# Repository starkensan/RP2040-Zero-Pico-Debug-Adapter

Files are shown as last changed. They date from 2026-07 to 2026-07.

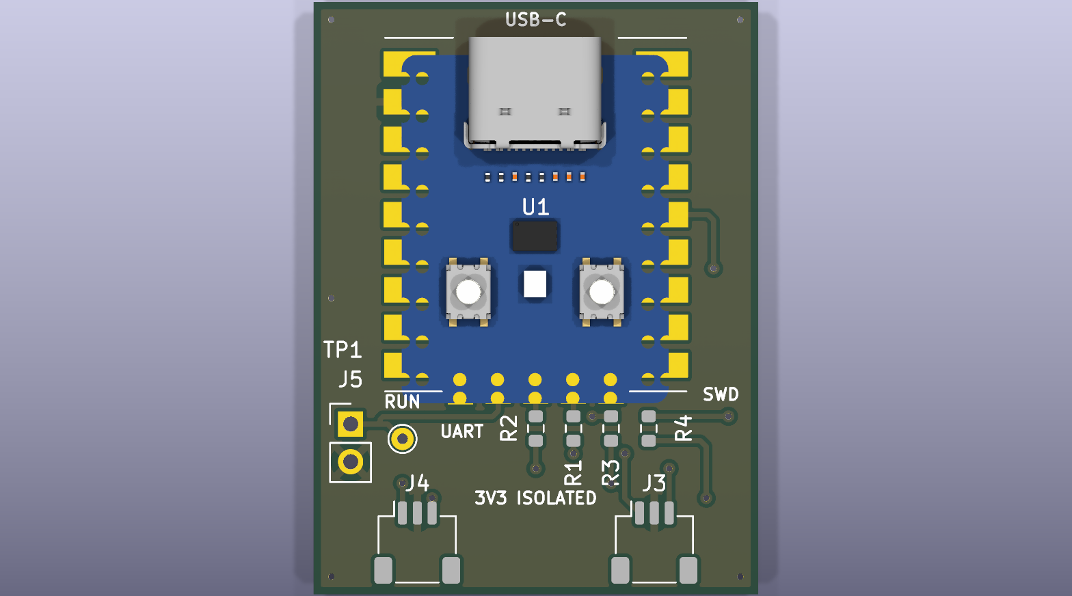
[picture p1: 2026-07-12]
RP2040-Zero-Pico-Debug-Adapter-preview.png

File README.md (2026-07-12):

# RP2040-Zero-Pico-Debug-Adapter

KiCad 9 project for a small 2-layer adapter PCB that mounts a Waveshare RP2040-Zero module and exposes the debugprobe-zero SWD/UART signals for Raspberry Pi Pico targets.

## Signal Mapping

| RP2040-Zero signal | Adapter part | Target connector pin |
| --- | --- | --- |
| GP10 | R1 100 ohm series | J3 pin 1 SWCLK |
| GND | direct | J3 pin 2 GND |
| GP11 | R2 100 ohm series | J3 pin 3 SWDIO |
| GP4 | R3 100 ohm series | J4 pin 1 TX from probe |
| GND | direct | J4 pin 2 GND |
| GP5 | R4 100 ohm series | J4 pin 3 RX to probe |
| GP12 | direct | J5 pin 1 RUN/RESET and TP1 |
| GND | direct | J5 pin 2 GND |

The RP2040-Zero 3V3 pin is not routed to the target connectors by default.

## Connectors

- `J3` Pico SWD JST-SH, 1.00 mm pitch:
  - Pin 1: `SWCLK`
  - Pin 2: `GND`
  - Pin 3: `SWDIO`
- `J4` UART JST-SH, 1.00 mm pitch:
  - Pin 1: `TX` from probe
  - Pin 2: `GND`
  - Pin 3: `RX` to probe
- `J5` optional 2-pin RUN/RESET header:
  - Pin 1: `RUN_RESET`
  - Pin 2: `GND`

## Build Notes

- Board size: 30 mm x 40 mm, portrait orientation.
- Copper layers: 2.
- GND copper pours: filled zones on both F.Cu and B.Cu.
- Signal tracks: 0.35 mm nominal.
- Ground routes: 0.6 mm nominal on the back layer.
- SWD and UART use 100 ohm source-termination resistors in 0603 (1608 metric) packages. RUN/RESET is connected directly.
- With the RP2040-Zero USB-C connector at the top, J5 is at the left-center, UART is at the lower-left, and SWD is at the lower-right. Both JST-SH cable openings face outward/downward.
- RP2040-Zero is represented as one 23-pin `U1` symbol and the project-local `Adapter:Waveshare_RP2040-Zero` footprint.
- The footprint supports castellated SMD mounting and optional 0.8 mm through holes. Verify the USB-C orientation before soldering.

## Files

- `RP2040-Zero-Pico-Debug-Adapter.kicad_pro`: KiCad project.
- `RP2040-Zero-Pico-Debug-Adapter.kicad_sch`: schematic note/net-map sheet.
- `RP2040-Zero-Pico-Debug-Adapter.kicad_pcb`: placed and routed PCB layout.
- `RP2040-Zero-Pico-Debug-Adapter.net`: KiCad netlist exported from the schematic.
- `RP2040-Zero-Pico-Debug-Adapter_bom.csv`: bill of materials.
- `generate_kicad_project.py`: reproducible PCB generator using KiCad 9 `pcbnew`.
- `generate_kicad_schematic.py`: reproducible schematic/local symbol generator.
- `RP2040-Zero.kicad_sym`: downloaded RP2040-Zero symbol library.
- `Adapter.pretty/`: project-local footprints, including the downloaded and verified RP2040-Zero footprint.
- `3dmodels/Waveshare_RP2040-Zero.step`: official Waveshare 3D model used by the RP2040-Zero footprint.
- `FOOTPRINT_SOURCES.md`: footprint source notes and URLs.

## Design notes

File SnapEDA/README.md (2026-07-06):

# SnapEDA RP2040-ZERO Model

Source page:

https://www.snapeda.com/parts/RP2040-ZERO/Waveshare%20Electronics/view-part/

This page is the intended source for the Waveshare `RP2040-ZERO` KiCad symbol, footprint, and 3D model.

Automated download from this environment was blocked by SnapEDA/Cloudflare with HTTP 403, so the SnapEDA model files are not committed here yet. To use the SnapEDA model:

1. Open the source page in a browser.
2. Download the KiCad CAD model package.
3. Extract the KiCad footprint/symbol files.
4. Copy the extracted footprint into `Internet_Footprints.pretty/` or a new project-local `.pretty` library.
5. Update `fp-lib-table` and the schematic footprint field if the footprint name differs.

The current project instead uses online-downloaded KiCad official footprints for the headers, JST-SH connector, resistors, test point, and mounting holes.

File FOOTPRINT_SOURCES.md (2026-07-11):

# Footprint and Source Notes

## Sources Checked

- Waveshare RP2040-Zero wiki: official product page with pinout and dimensions sections.
  - https://www.waveshare.com/wiki/RP2040-Zero
- Waveshare RP2040-Zero official schematic PDF.
  - https://files.waveshare.com/upload/4/4c/RP2040_Zero.pdf
- Waveshare RP2040-Zero official STEP model.
  - https://files.waveshare.com/upload/f/f7/RP2040_Zero_stp.zip
  - Stored as `3dmodels/Waveshare_RP2040-Zero.step` and referenced directly by the local footprint.
- dj505 RP2040-Zero KiCad symbol and footprint library, downloaded at commit `b22a0c1afb350dda50ebb7cf2d9c5f3dd3e419ce`.
  - https://github.com/dj505/RP2040-Zero-KiCAD
  - License: CERN Open Hardware Licence Version 2 - Permissive; local copy in `LICENSES/RP2040-Zero-KiCAD-CERN-OHL-P-2.0.txt`.
- KiCad official footprint library entry for the JST-SH connector used by this project.
  - https://gitlab.com/kicad/libraries/kicad-footprints/-/blob/master/Connector_JST.pretty/JST_SH_SM03B-SRSS-TB_1x03-1MP_P1.00mm_Horizontal.kicad_mod

## Local Footprints

- `Adapter.pretty/Waveshare_RP2040-Zero.kicad_mod`
  - Downloaded from dj505's public KiCad library and checked against Waveshare's official 18.00 mm x 23.50 mm dimensions and 23-pin pinout.
  - Supports the castellated SMD pads and optional 0.8 mm through holes.
  - The source footprint's internal `Edge.Cuts` cutout was removed because this carrier board does not require a module-area cutout.
  - Applied to `U1`; used nets are `GP10` (pin 22), `GP11` (21), `GP12` (20), `GP4` (14), `GP5` (15), and `GND` (2).

## Local Symbol

- `RP2040-Zero.kicad_sym`
  - Downloaded from the same dj505 library.
  - Default footprint and official Waveshare datasheet fields were added locally; the module GND pin was changed from `power_in` to `passive` to match this unpowered adapter's ERC semantics.
  - Registered as `RP2040_Zero:RP2040-Zero` and applied to `U1`.

## Stock KiCad Footprints Used

The remaining footprints are stock KiCad 9 footprints, with the JST-SH connector cross-checked against the KiCad official online footprint library:

- `Connector_JST:JST_SH_SM03B-SRSS-TB_1x03-1MP_P1.00mm_Horizontal`
- `Resistor_SMD:R_0603_1608Metric`
- `Connector_PinHeader_2.54mm:PinHeader_1x02_P2.54mm_Vertical`
- `TestPoint:TestPoint_THTPad_D1.5mm_Drill0.7mm`

## Netlist

The KiCad netlist is generated from `RP2040-Zero-Pico-Debug-Adapter.kicad_sch`:

```sh
kicad-cli sch export netlist --format kicadsexpr \
  --output RP2040-Zero-Pico-Debug-Adapter.net \
  RP2040-Zero-Pico-Debug-Adapter.kicad_sch
```

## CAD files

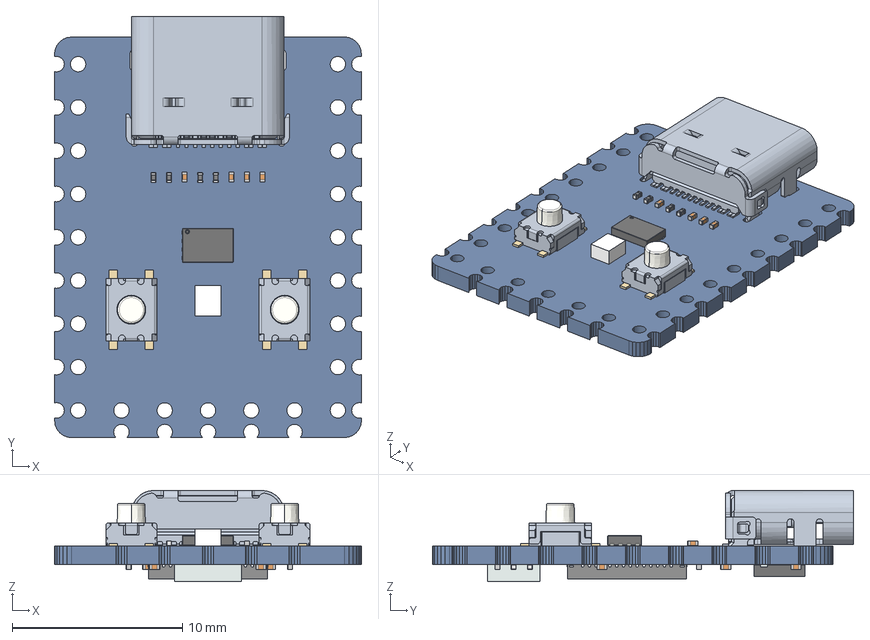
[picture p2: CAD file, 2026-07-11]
3dmodels/Waveshare_RP2040-Zero.step
18.0 x 24.7 x 5.34 mm
BOARD
ANSCHL_X_FCSSE_1 x 9
K_X_F6RPER_1 x 9
EXTRUDED-32530
USER_LIBRARY-CHIP_CAP_MLCC_0201 x 19
EXTRUDED-36548
USER_LIBRARY-RP2040_QFN56_04
USER_LIBRARY-8MA3_1
USER_LIBRARY-8MA3_2
EXTRUDED-175432
EXTRUDED-175804 x 5
TS-1185EC-A-E-A-1 x 2
EXTRUDED-374538 x 10

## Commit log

2026-07-06 Initial KiCad adapter project
    [RP2040-Zero-Pico-Debug-Adapter.kicad_pcb, RP2040-Zero-Pico-Debug-Adapter.kicad_sch, RP2040-Zero-Pico-Debug-Adapter.step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]
2026-07-06 Add proper KiCad schematic
    [RP2040-Zero-Pico-Debug-Adapter.kicad_sch]
2026-07-06 Add netlist and footprint sources
2026-07-06 Use downloaded online footprints
    [RP2040-Zero-Pico-Debug-Adapter.kicad_pcb, RP2040-Zero-Pico-Debug-Adapter.kicad_sch, RP2040-Zero-Pico-Debug-Adapter.step]
2026-07-11 Refine RP2040-Zero debug adapter layout
    [RP2040-Zero-Pico-Debug-Adapter.kicad_pcb, RP2040-Zero-Pico-Debug-Adapter.kicad_sch, RP2040-Zero-Pico-Debug-Adapter_bom.csv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]
2026-07-12 Rework PCB into compact portrait layout
    [RP2040-Zero-Pico-Debug-Adapter.kicad_pcb]
